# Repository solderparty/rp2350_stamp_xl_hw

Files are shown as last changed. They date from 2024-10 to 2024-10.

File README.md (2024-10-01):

# The RP2350 Stamp XL

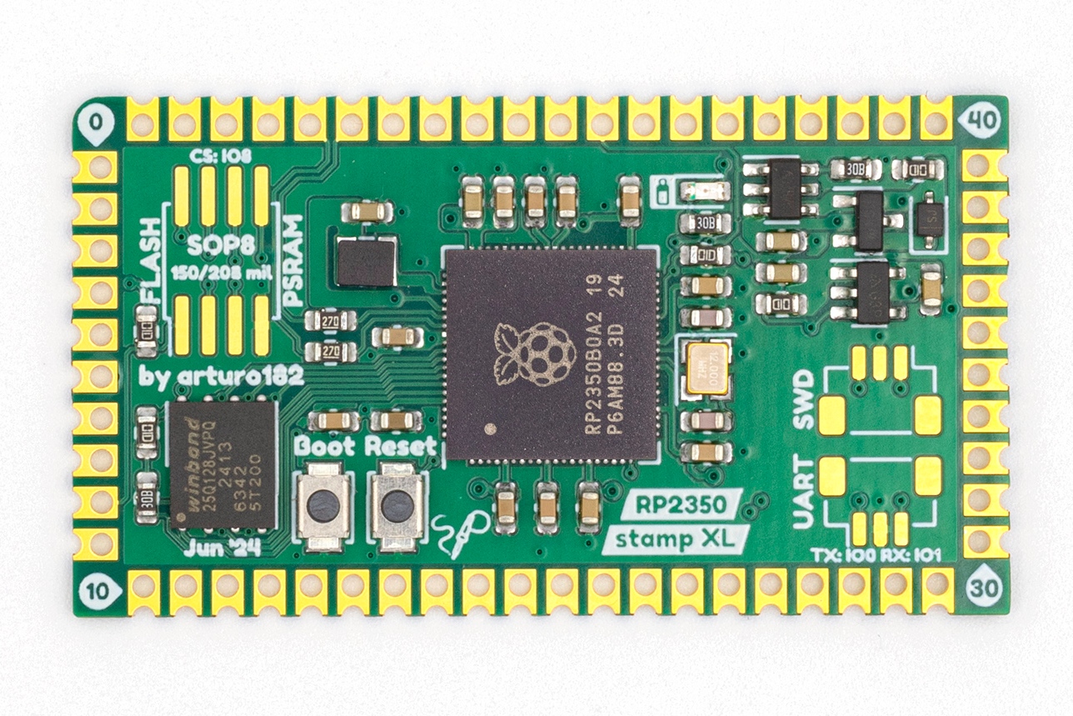
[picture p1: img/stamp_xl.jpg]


The Stamp was created to allow you to use the **Raspberry Pi RP2350B** in your designs without having to solder small-pitch QFN chips or worry about lots of external circuitry.

The RP2350 Stamp XL is partially pad-compatible with the smaller Stamps. The left-side pads as well as half of the top and bottom ones are exactly the same.

All you need to get you started is a 5V supply or a LiPo battery. The Stamp will take care of the charging and switching the power sources.

The castellated edges with **2mm pitch** can be hand-soldered directly to a Carrier board, used with pin headers for more flexibility, or connected without soldering using [FlexyPins](https://docs.solder.party/flexypin), which are spring connectors designed for modules with castellated edges. You can find footprints for many PCB programs [here](https://github.com/solderparty/rp2xxx_stamp_footprints).

We were also able to squeeze in two new functional pads: an LDO EN pad, connected to the LDOs EN signal, and a BAT STAT, connected to the LiPo charger's STAT pin.

At only **1 by 1¾ inch**, the Stamp XL packs a lot of features:
* **16MB of FLASH**
* **500mA 3.3V LDO**
* **All 48 GPIOs broken out**
* **A footprint for a second QSPI FLASH/PSRAM**
* Footprints for SWD and UART JST connectors, pin-compatible with the Raspberry Pi Debug Probe
* LiPo supply and charging circuit (with charging LED)
* USB broken out
* SWD broken out
* Reset Button
* Bootsel Button
* 12MHz crystal

and of course, everything that comes with the Raspberry Pi RP2350 itself:
* Dual core ARM Cortex-M33 or Hazard3 @ 150MHz
* 520kB SRAM
* 2 UARTs
* 2 SPIs
* 2 I2Cs
* 24 PWM channels
* 12 PIO state machines
* 1 HSTX peripheral
* USB with Host and Device support

The RP2350 comes with a pre-programmed ROM UF2 Bootloader, by pulling the BOOTSEL pin low and resetting, or by double-pressing the RESET button (if the FW supports it), you can upload new firmware using the USB disk drive.

In addition to the Stamps we also offer a few reference designs, see the Carriers in the [Stamp-related category](https://docs.solder.party/rp2xxx-stamp-related) as well as our [Flux projects](https://docs.solder.party/flux).

The CircuitPython firmware for the Stamp comes with a built-in board files for the Carriers, for example you can access the RP2040 Stamp Carrier pins and interfaces by using `import stamp_carrier_board as board`. See [here](https://github.com/adafruit/circuitpython/tree/main/ports/raspberrypi/boards/solderparty_rp2040_stamp) for all the available Carrier board files.

# Links

For more information visit https://rp2350-stamp-xl.solder.party/

Buy it on Lectronz (https://lectronz.com/products/rp2350-stamp-xl)

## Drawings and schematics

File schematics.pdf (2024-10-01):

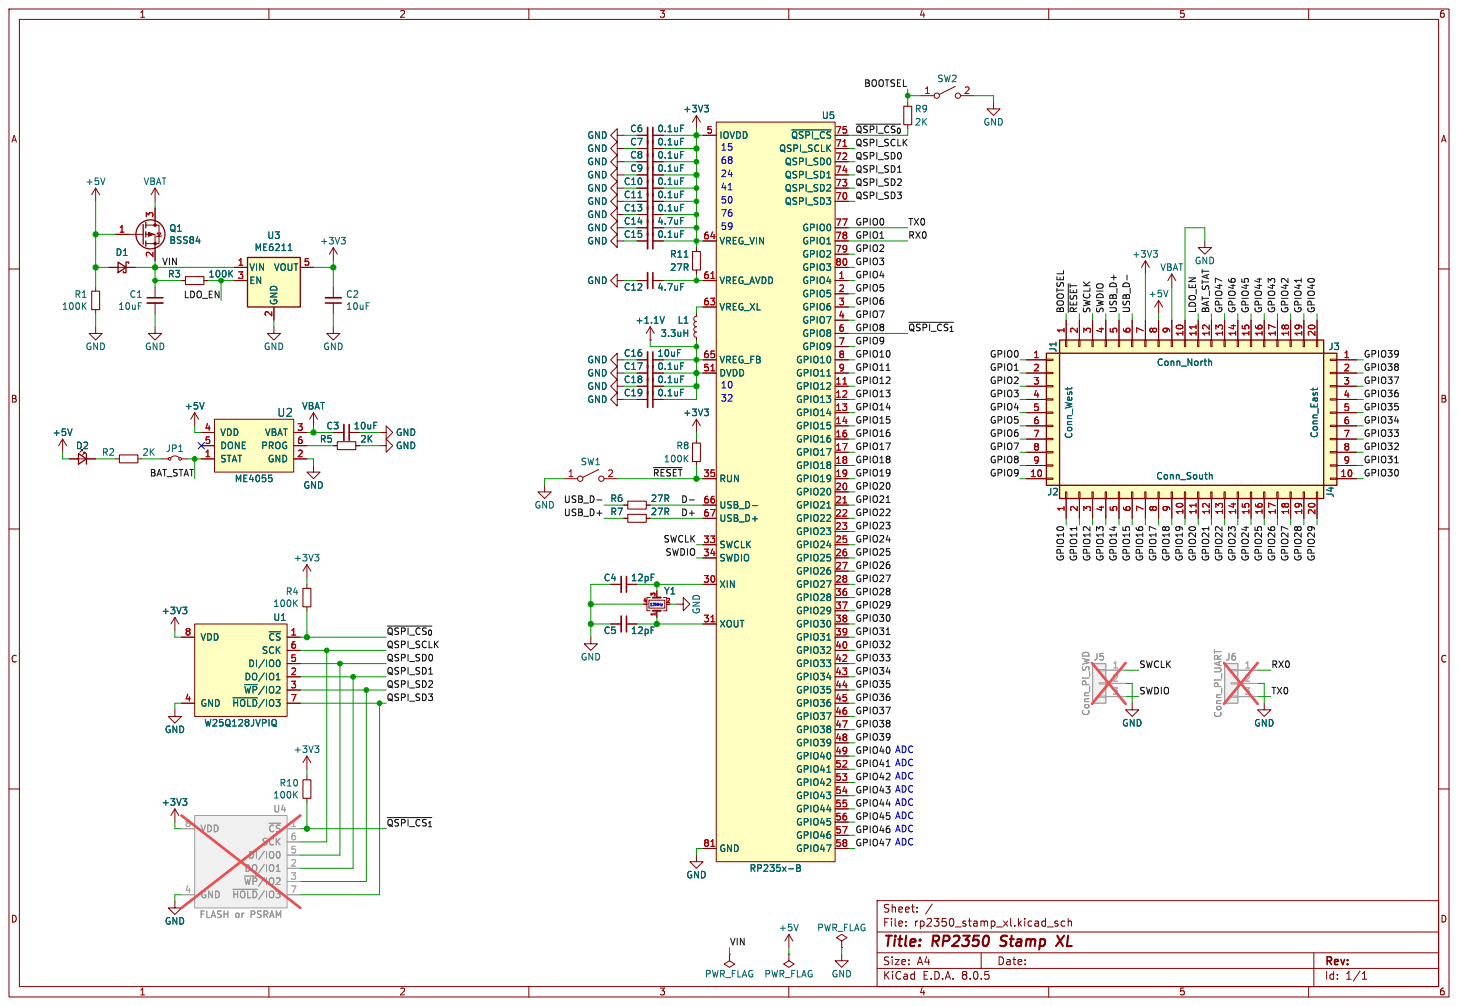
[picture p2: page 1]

2 EN 3 VOUT 5 +3V3 C9 0.1uF C7 0.1uF C8 0.1uF C6 0.1uF C11 0.1uF C13 0.1uF C10 0.1uF C14 4.7uF GND GND GND GND GND GND GND GND

2 EN 3 VOUT 5 U3 ME6211 GND GND GND GND

Id: 1/1 Title: RP2350 Stamp XL

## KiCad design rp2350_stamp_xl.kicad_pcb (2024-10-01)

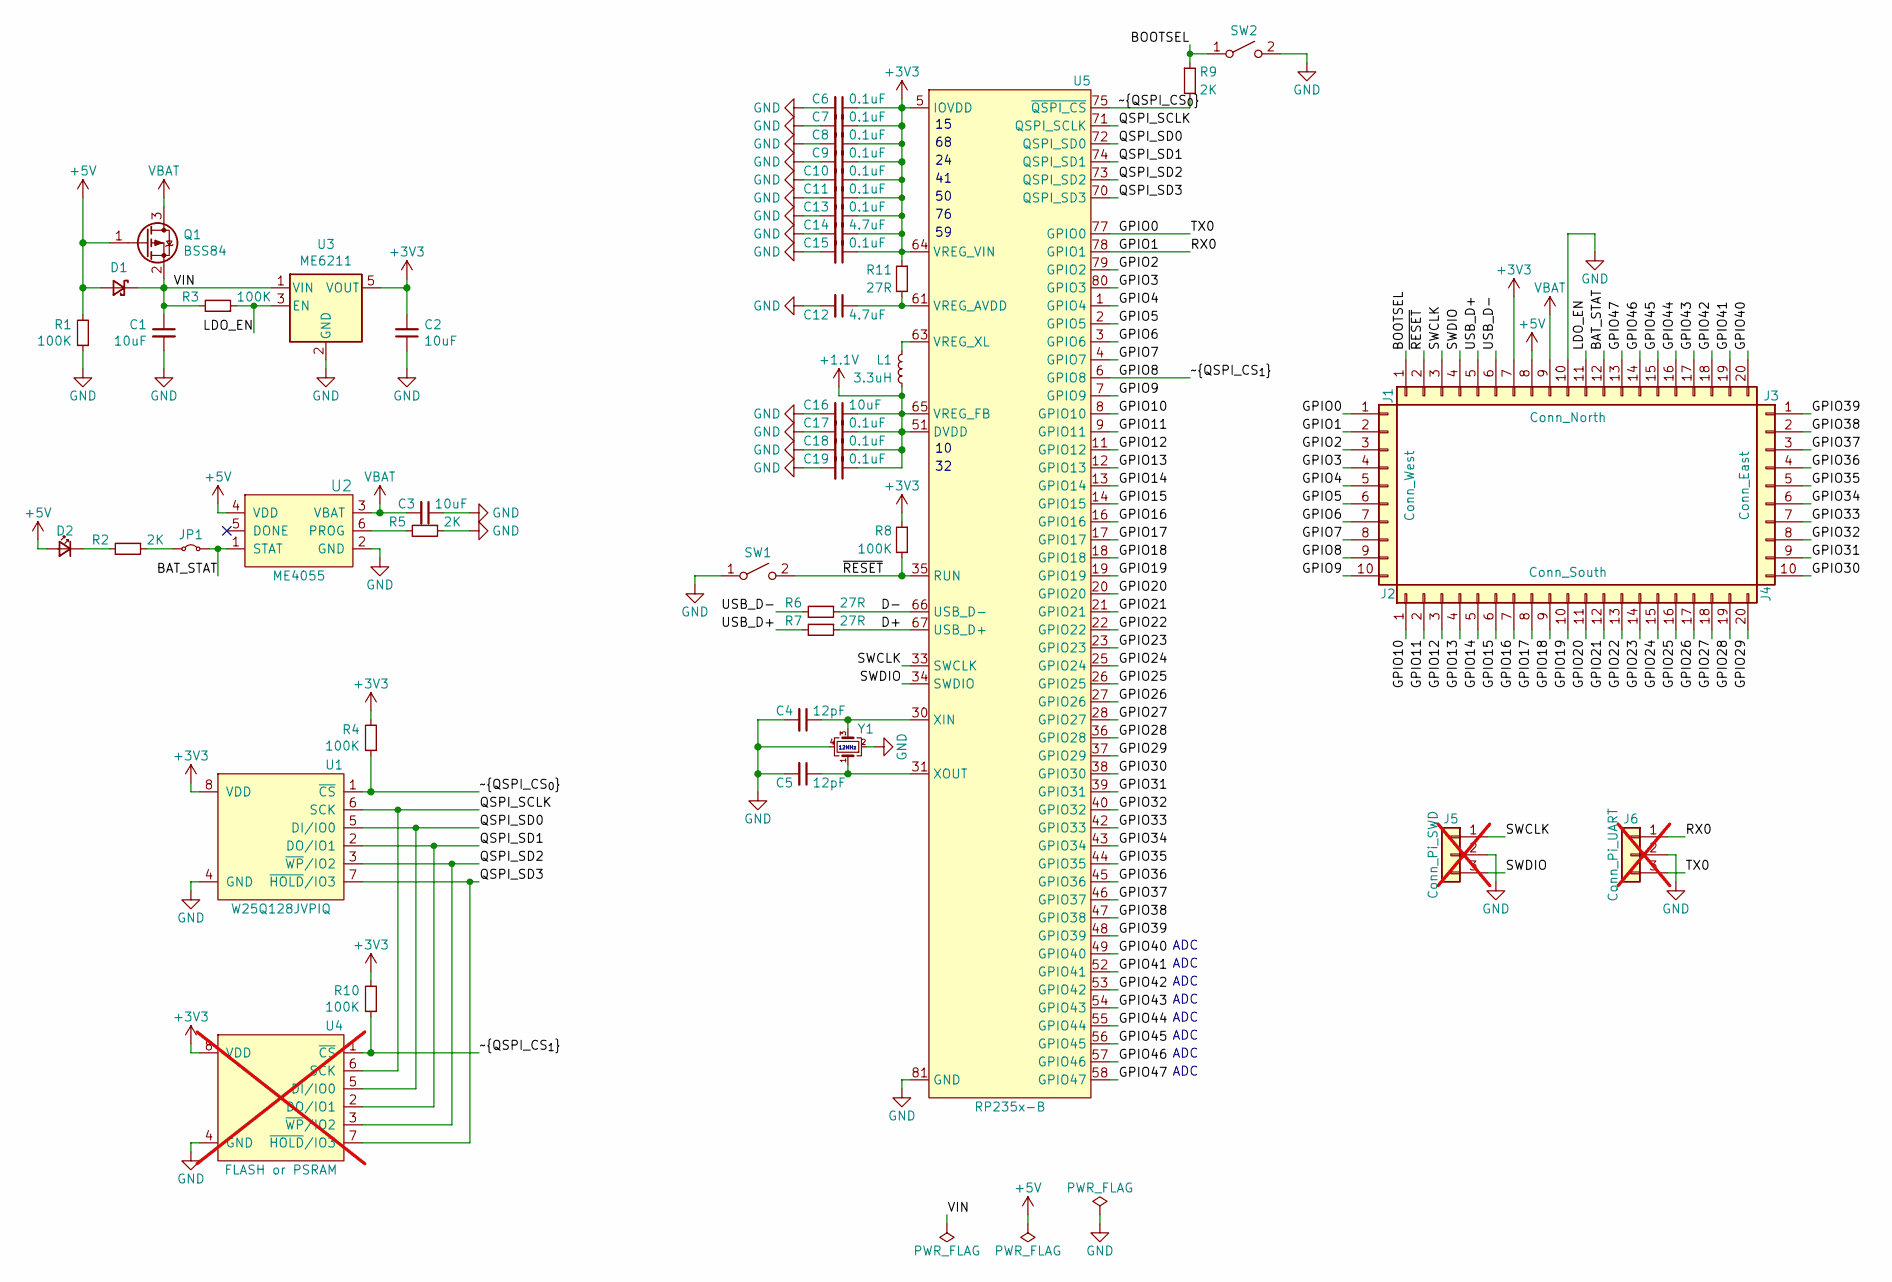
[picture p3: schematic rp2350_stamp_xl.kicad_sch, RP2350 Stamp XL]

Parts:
C1, C2, C3, C16: 10uF; C_0603_1608Metric
C4, C5: 12pF; C_0603_1608Metric
C6, C7, C8, C9, C10, C11, C13, C15, C17, C18, C19: 0.1uF; C_0603_1608Metric
C12, C14: 4.7uF; C_0603_1608Metric
D1: D_Schottky_Small; D_SOD-323; LCSC C114023
D2: LED_CHR; LED_0603_1608Metric
J1: Conn_North; Castellated_1x20_P2.00mm_Vertical
J2: Conn_West; Castellated_1x10_P2.00mm_Vertical
J3: Conn_East; Castellated_1x10_P2.00mm_Vertical
J4: Conn_South; Castellated_1x20_P2.00mm_Vertical
J5: Conn_Pi_SWD; JST_SH_BM03B-SRSS-TB_1x03-1MP_P1.00mm_Vertical; LCSC C7433439; not fitted
J6: Conn_Pi_UART; JST_SH_BM03B-SRSS-TB_1x03-1MP_P1.00mm_Vertical; LCSC C7433439; not fitted
JP1: SJ_STAT_LED; SolderJumper-2_P1.3mm_Bridged_RoundedPad1.0x1.5mm
L1: 3.3uH; L_Wuerth_MAPI-2512; LCSC C5832359
Q1: BSS84; SOT-23; LCSC C85202
R1, R3, R4, R8, R10: 100K; R_0603_1608Metric
R2, R5, R9: 2K; R_0603_1608Metric
R6, R7, R11: 27R; R_0603_1608Metric
SW1: SW_RESET; SW_SPST_B3U-1000P; LCSC C561514
SW2: SW_BOOTSEL; SW_SPST_B3U-1000P; LCSC C561514
U1: W25Q128JVPIQ; WSON-8-1EP_6x5mm_P1.27mm_EP3.4x4mm; LCSC C190862
U2: ME4055; SOT-23-6; LCSC C82121
U3: ME6211; SOT-23-5; LCSC C82942
U4: FLASH or PSRAM; SSOP-8_5.25x5.24mm_P1.27mm; not fitted
U5: RP235x-B; QFN-80_EP_10x10_Pitch0.4mm
Y1: CM4012M00012001; Crystal_SMD_2520-4Pin_2.5x2.0mm; LCSC C7294611

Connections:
+1.1V: C16.1, C17.1, C18.1, C19.1, L1.1, U5.10 (DVDD), U5.32 (DVDD), U5.51 (DVDD), U5.65 (VREG_FB)
+3V3: C2.2, C6.1, C7.1, C8.1, C9.1, C10.1, C11.1, C13.1, C14.1, C15.1, J1.7, R4.2, R8.1, R10.2, R11.1, U1.8 (VDD), U3.5 (VOUT), U4.8 (VDD), U5.5 (IOVDD), U5.15 (IOVDD), U5.24 (IOVDD), U5.29 (IOVDD), U5.41 (IOVDD), U5.50 (IOVDD), U5.59 (IOVDD), U5.60 (IOVDD), U5.64 (VREG_VIN), U5.68 (IOVDD), U5.69 (IOVDD), U5.76 (IOVDD)
+5V: D1.2 (A), D2.2 (A), J1.8, Q1.1 (G), R1.2, U2.4 (VDD)
/BAT_STAT: J1.12, JP1.2 (B), U2.1 (STAT)
/BOOTSEL: J1.1, R9.1, SW2.1 (A)
/D+: R7.1, U5.67 (USB_D+)
/D-: R6.1, U5.66 (USB_D-)
/GPIO0: J2.1, J6.3, U5.77 (GPIO0)
/GPIO1: J2.2, J6.1, U5.78 (GPIO1)
/GPIO2: J2.3, U5.79 (GPIO2)
/GPIO3: J2.4, U5.80 (GPIO3)
/GPIO4: J2.5, U5.1 (GPIO4)
/GPIO5: J2.6, U5.2 (GPIO5)
/GPIO6: J2.7, U5.3 (GPIO6)
/GPIO7: J2.8, U5.4 (GPIO7)
/GPIO8: J2.9, R10.1, U4.1 (~CS), U5.6 (GPIO8)
/GPIO9: J2.10, U5.7 (GPIO9)
/GPIO10: J4.1, U5.8 (GPIO10)
/GPIO11: J4.2, U5.9 (GPIO11)
/GPIO12: J4.3, U5.11 (GPIO12)
/GPIO13: J4.4, U5.12 (GPIO13)
/GPIO14: J4.5, U5.13 (GPIO14)
/GPIO15: J4.6, U5.14 (GPIO15)
/GPIO16: J4.7, U5.16 (GPIO16)
/GPIO17: J4.8, U5.17 (GPIO17)
/GPIO18: J4.9, U5.18 (GPIO18)
/GPIO19: J4.10, U5.19 (GPIO19)
/GPIO20: J4.11, U5.20 (GPIO20)
/GPIO21: J4.12, U5.21 (GPIO21)
/GPIO22: J4.13, U5.22 (GPIO22)
/GPIO23: J4.14, U5.23 (GPIO23)
/GPIO24: J4.15, U5.25 (GPIO24)
/GPIO25: J4.16, U5.26 (GPIO25)
/GPIO26: J4.17, U5.27 (GPIO26)
/GPIO27: J4.18, U5.28 (GPIO27)
/GPIO28: J4.19, U5.36 (GPIO28)
/GPIO29: J4.20, U5.37 (GPIO29)
/GPIO30: J3.10, U5.38 (GPIO30)
/GPIO31: J3.9, U5.39 (GPIO31)
/GPIO32: J3.8, U5.40 (GPIO32)
/GPIO33: J3.7, U5.42 (GPIO33)
/GPIO34: J3.6, U5.43 (GPIO34)
/GPIO35: J3.5, U5.44 (GPIO35)
/GPIO36: J3.4, U5.45 (GPIO36)
/GPIO37: J3.3, U5.46 (GPIO37)
/GPIO38: J3.2, U5.47 (GPIO38)
/GPIO39: J3.1, U5.48 (GPIO39)
/GPIO40: J1.20, U5.49 (GPIO40)
/GPIO41: J1.19, U5.52 (GPIO41)
/GPIO42: J1.18, U5.53 (GPIO42)
/GPIO43: J1.17, U5.54 (GPIO43)
/GPIO44: J1.16, U5.55 (GPIO44)
/GPIO45: J1.15, U5.56 (GPIO45)
/GPIO46: J1.14, U5.57 (GPIO46)
/GPIO47: J1.13, U5.58 (GPIO47)
/LDO_EN: J1.11, R3.1, U3.3 (EN)
/QSPI_SCLK: U1.6 (SCK), U4.6 (SCK), U5.71 (QSPI_SCLK)
/QSPI_SD0: U1.5 (DI/IO0), U4.5 (DI/IO0), U5.72 (QSPI_SD0)
/QSPI_SD1: U1.2 (DO/IO1), U4.2 (DO/IO1), U5.74 (QSPI_SD1)
/QSPI_SD2: U1.3 (~WP/IO2), U4.3 (~WP/IO2), U5.73 (QSPI_SD2)
/QSPI_SD3: U1.7 (~HOLD/IO3), U4.7 (~HOLD/IO3), U5.70 (QSPI_SD3)
/SWCLK: J1.3, J5.1, U5.33 (SWCLK)
/SWDIO: J1.4, J5.3, U5.34 (SWDIO)
/USB_D+: J1.5, R7.2
/USB_D-: J1.6, R6.2
/VIN: C1.1, D1.1 (K), Q1.2 (S), R3.2, U3.1 (VIN)
/~QSPI_CS_{0}: R4.1, R9.2, U1.1 (~CS), U5.75 (~QSPI_CS)
/~RESET: J1.2, R8.2, SW1.2 (B), U5.35 (RUN)
GND: C1.2, C2.1, C3.1, C4.2, C5.2, C6.2, C7.2, C8.2, C9.2, C10.2, C11.2, C12.2, C13.2, C14.2, C15.2, C16.2, C17.2, C18.2, C19.2, J1.10, J5.2, J6.2, R1.1, R5.1, SW1.1 (A), SW2.2 (B), U1.4 (GND), U1.9 (GND), U2.2 (GND), U3.2 (GND), U4.4 (GND), U4.9 (GND), U5.62 (GND), U5.81 (GND), Y1.2, Y1.4
unnamed: D2.1 (K), R2.2
unnamed: JP1.1 (A), R2.1
unnamed: R5.2, U2.6 (PROG)
unnamed: C12.1, R11.2, U5.61 (VREG_AVDD)
unnamed: L1.2, U5.63 (VREG_XL)
unnamed: C4.1, U5.30 (XIN), Y1.3
unnamed: C5.1, U5.31 (XOUT), Y1.1
VBAT: C3.2, J1.9, Q1.3 (D), U2.3 (VBAT)

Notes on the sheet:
ADC
12MHz

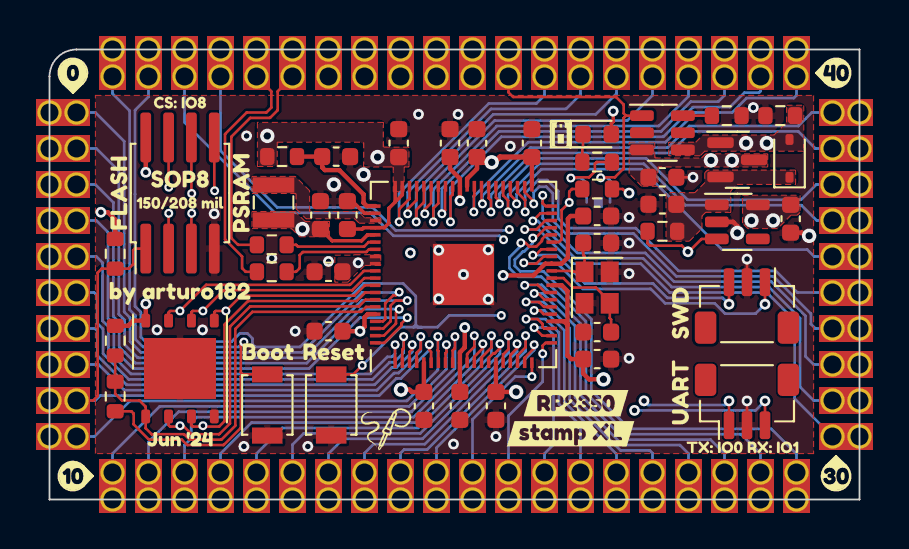
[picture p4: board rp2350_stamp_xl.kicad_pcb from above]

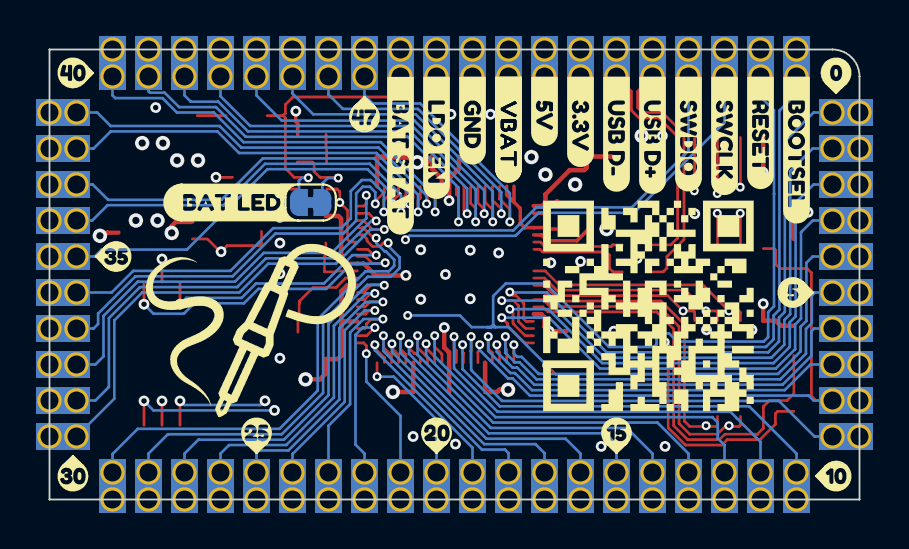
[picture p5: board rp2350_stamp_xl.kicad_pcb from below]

Board: 4 copper layers, 45.0 x 25.0 mm, 93 parts (26 on the bottom side), 77 nets.

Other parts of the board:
SP-LOGO: LOGO; SolderParty-New-Logo_3x2.5mm_SilkScreen
kibuzzard-65C6A7E6: G***; kibuzzard-65C6A7E6
kibuzzard-65C6A7EF: G***; kibuzzard-65C6A7EF
kibuzzard-65C6A855: G***; kibuzzard-65C6A855
kibuzzard-65C6A858: G***; kibuzzard-65C6A858
kibuzzard-65C59B9B: G***; kibuzzard-65C59B9B
kibuzzard-65C557A7: G***; kibuzzard-65C557A7
kibuzzard-65C55791: G***; kibuzzard-65C55791
kibuzzard-65CABD6A: G***; kibuzzard-65CABD6A
kibuzzard-65CABE96: G***; kibuzzard-65CABE96
kibuzzard-65CABECC: G***; kibuzzard-65CABECC
kibuzzard-653BD2BD: G***; kibuzzard-653BD2BD
kibuzzard-653BD2D7: G***; kibuzzard-653BD2D7
kibuzzard-653BD2FF: G***; kibuzzard-653BD2FF
kibuzzard-653BD3DA: G***; kibuzzard-653BD3DA
kibuzzard-653BD34E: G***; kibuzzard-653BD34E
kibuzzard-653BD35B: G***; kibuzzard-653BD35B
kibuzzard-653BD327: G***; kibuzzard-653BD327
kibuzzard-653BD339: G***; kibuzzard-653BD339
kibuzzard-653BD344: G***; kibuzzard-653BD344
kibuzzard-653BD355: G***; kibuzzard-653BD355
kibuzzard-653BD365: G***; kibuzzard-653BD365
kibuzzard-6577C6A3: G***; kibuzzard-6577C6A3
kibuzzard-6577C69C: G***; kibuzzard-6577C69C
kibuzzard-6578FE34: G***; kibuzzard-6578FE34
kibuzzard-6605B0A1: G***; kibuzzard-6605B0A1
kibuzzard-6605B0D5: G***; kibuzzard-6605B0D5
kibuzzard-6695ACF2, kibuzzard-6695ACF2#2: G***; kibuzzard-6695ACF2
kibuzzard-6695AD18, kibuzzard-6695AD18#2: G***; kibuzzard-6695AD18
kibuzzard-6695BC9C: G***; kibuzzard-6695BC9C
kibuzzard-6695BCB6: G***; kibuzzard-6695BCB6
kibuzzard-6695BF60, kibuzzard-6695BF60#2: G***; kibuzzard-6695BF60
kibuzzard-6695BFEA, kibuzzard-6695BFEA#2: G***; kibuzzard-6695BFEA
kibuzzard-6695C3C8: G***; kibuzzard-6695C3C8
kibuzzard-6695C4C9: G***; kibuzzard-6695C4C9
kibuzzard-6695C24F: G***; kibuzzard-6695C24F
kibuzzard-6695C28C: G***; kibuzzard-6695C28C
kibuzzard-6695C219: G***; kibuzzard-6695C219
kibuzzard-6695C372: G***; kibuzzard-6695C372
svg2mod: G***; svg2mod

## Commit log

2024-02-13 Rev 1
    [rp2350_stamp_xl.kicad_pcb, rp2350_stamp_xl.kicad_sch]
2024-07-16 Rev 3
    - Rev 2 added logo and QR Code
    - Put chip name on the board
    - Fixup pin markers to be uniform
    - Add battery icon
    [rp2350_stamp_xl.kicad_pcb, rp2350_stamp_xl.kicad_sch]
2024-07-29 Rev 3.5
    Fixup power stuff according to RPi's recommendations
    [rp2350_stamp_xl.kicad_pcb, rp2350_stamp_xl.kicad_sch]
2024-10-01 Fix BOM info, add README and LICENSE
    [rp2350_stamp_xl.kicad_pcb, rp2350_stamp_xl.kicad_sch]
